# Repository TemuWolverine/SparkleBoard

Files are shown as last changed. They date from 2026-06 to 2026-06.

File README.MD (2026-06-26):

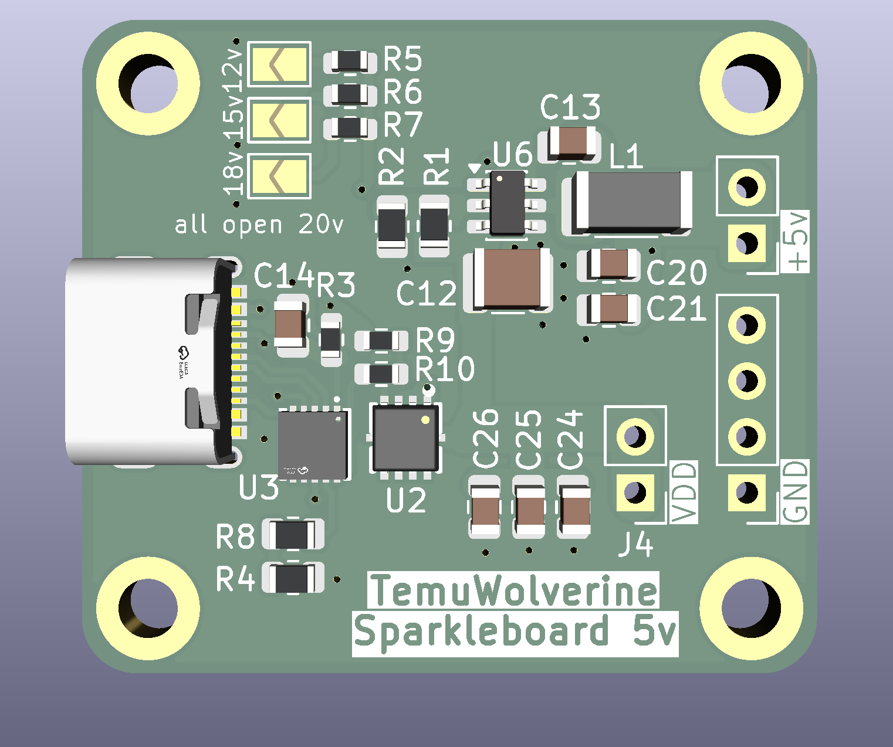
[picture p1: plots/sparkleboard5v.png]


# SparkleBoard 5v (WIP)
SparkleBoard is a USB-PD power board that provides two power rails - one is user selectable from 12v, 15v, 18v or 20v (if the USB-PD power brick supports it) by using jumpers. The other power rail is 5v for microcontrollers.

Amperage defaults to 2a, can be set to 3.25a by cutting JP1

## 5v  -> 3.3v
5v rail is provided via a buck converter - [AP63205](https://www.diodes.com/part/view/AP63205), an inexpensive fixed voltage buck converter from Diodes.

If you wanted 3.3v, this could be achieved by swapping out the chip for the AP63203, and changing the inductor to 3.9uH (from 4.7uH). The rest of the circuit design remains the same according to the manufacturer.

> Note: the AP63200/AP63201 are not fixed voltage output IC's and require additional circuitry with different values and are **NOT** drop in replacements.

## Datasheets
* [AP63205](https://www.diodes.com/datasheet/download/AP63200-AP63201-AP63203-AP63205.pdf)
* [HUSB238](https://www.hynetek.com/uploadfiles/site/219/news/aabbbbdb-48c9-4a44-a6dc-2c15f53282e6.pdf)

## References
* [Sparkfun Babybuck](https://github.com/sparkfun/Buck_Regulator_AP63203/tree/main) (AP6320***3***)
* [Adafruit HUSB238 breakout board](https://github.com/adafruit/Adafruit-USB-Type-C-Power-Delivery-Dummy-Breakout-PCB/tree/main)

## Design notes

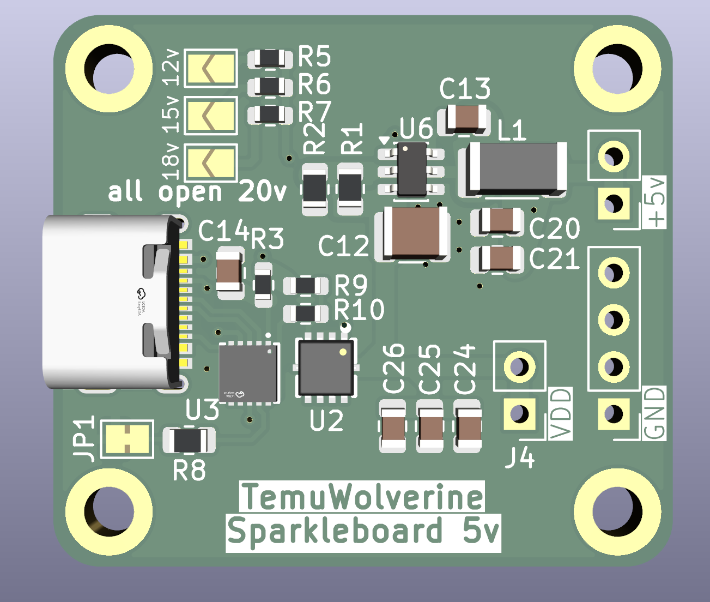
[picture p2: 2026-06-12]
image.png

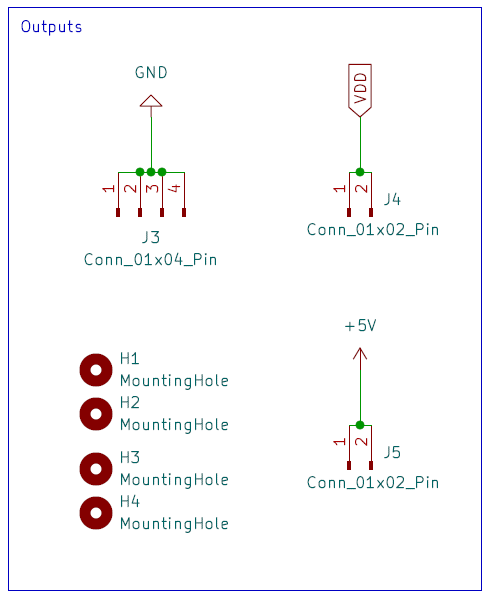
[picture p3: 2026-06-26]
plots/Pins.png

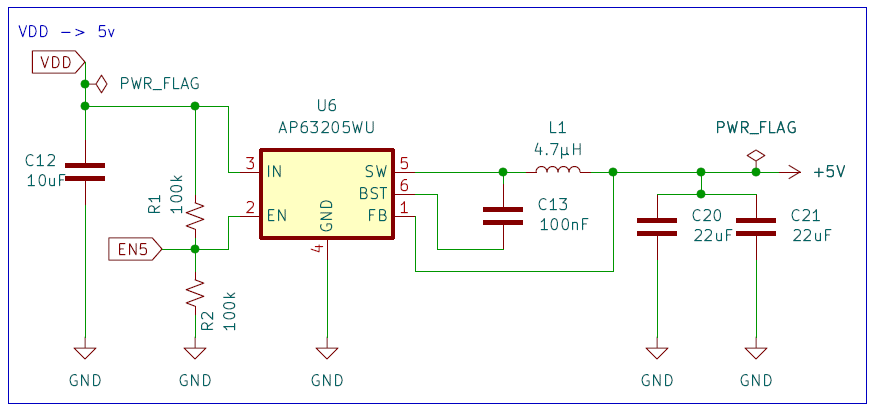
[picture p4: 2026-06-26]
plots/Buck.png

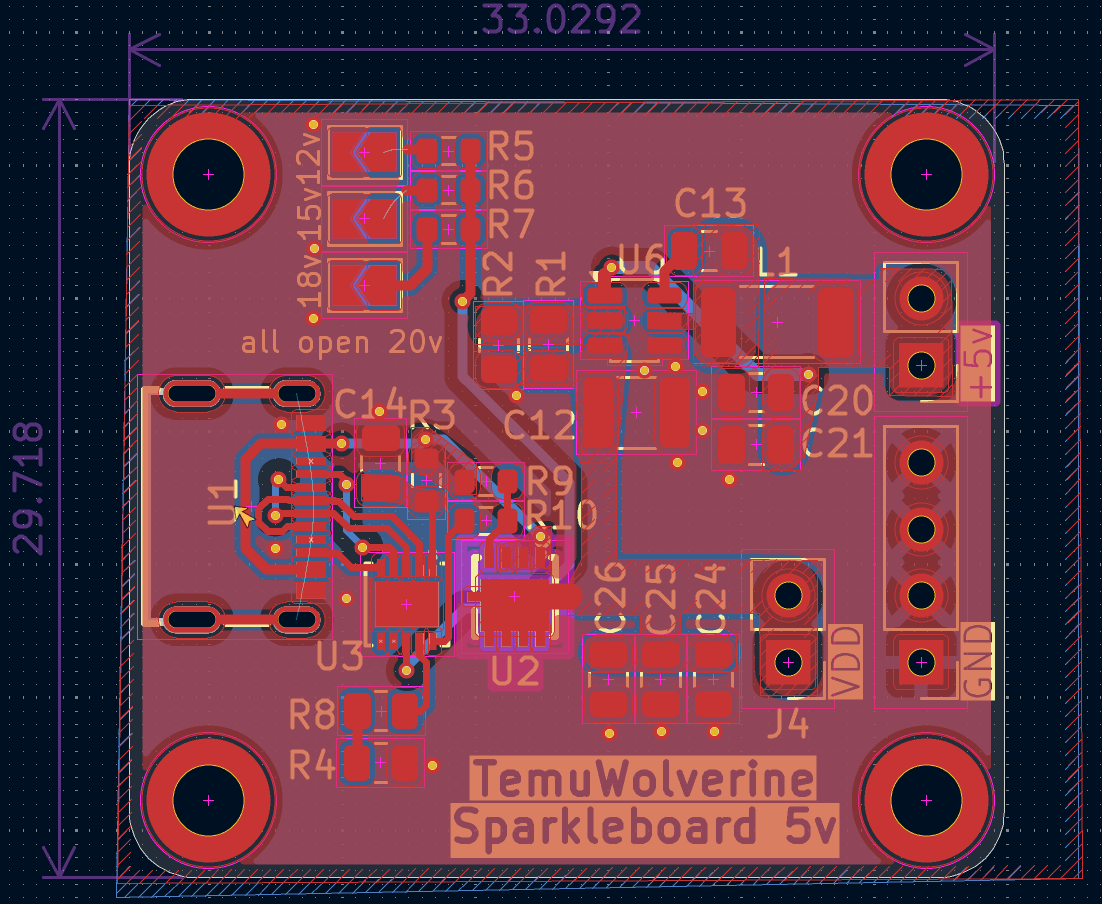
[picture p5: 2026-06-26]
plots/pcb_both.png

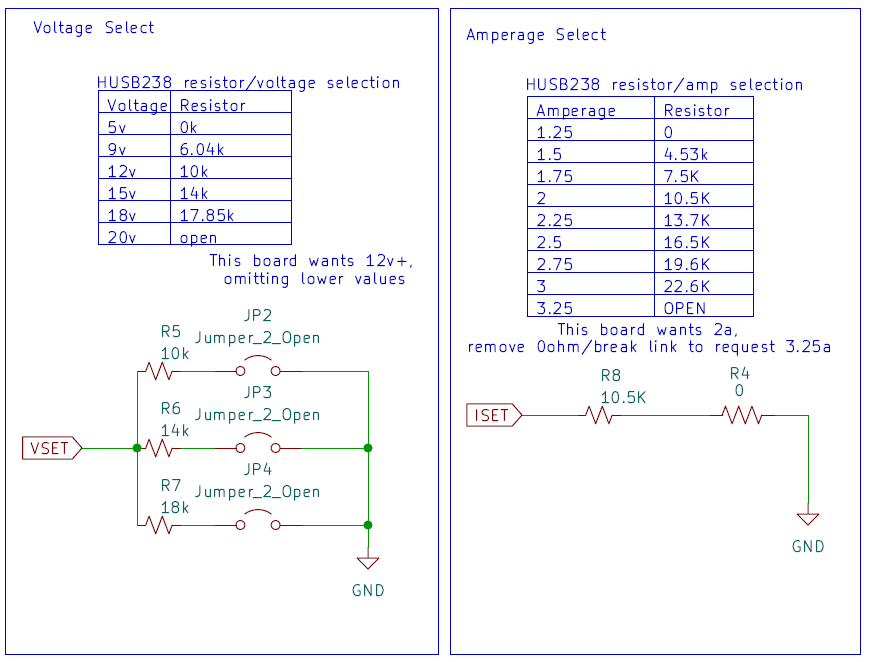
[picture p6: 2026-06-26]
plots/V_A_select.png

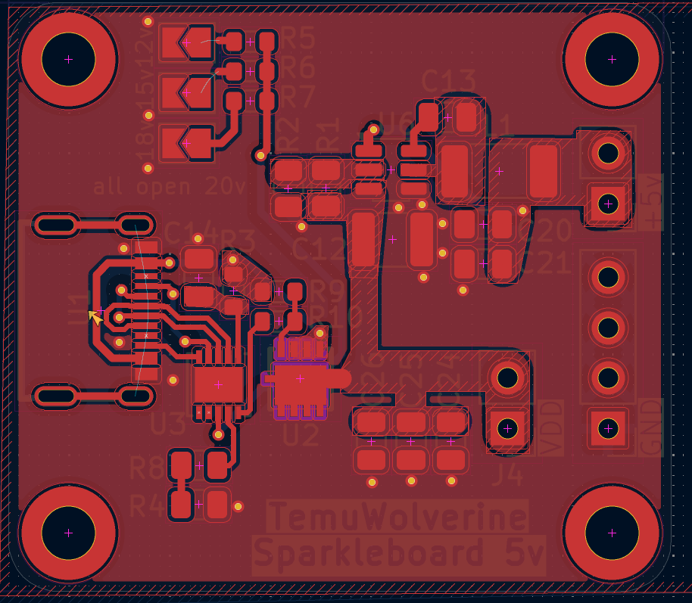
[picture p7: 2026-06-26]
plots/pcb_front.png

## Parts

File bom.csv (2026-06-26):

Designator | Footprint | Quantity | Value | LCSC Part #
C12 | 1210 | 1 | 10uF
C13 | 0805 | 1 | 100nF
C14 | 0805 | 1 | 1uF
C20, C21 | 0805 | 2 | 22uF
C24, C25, C26 | 0805 | 3 | 4.7uF
J3 | PinHeader_1x04_P2.54mm_Vertical | 1 | Conn_01x04_Pin
J4, J5 | PinHeader_1x02_P2.54mm_Vertical | 2 | Conn_01x02_Pin
JP2, JP3, JP4 | SolderJumper-2_P1.3mm_Open_TrianglePad1.0x1.5mm | 3 | Jumper_2_Open
L1 | 2010 | 1 | 4.7μH
R1, R2 | 0805 | 2 | 100k
R10 | 0603 | 1 | 5.1k
R3 | 0603 | 1 | 10
R4 | 0805 | 1 | 0
R5 | 0603 | 1 | 10k
R6 | 0603 | 1 | 14k
R7 | 0603 | 1 | 18k
R8 | 0805 | 1 | 10.5K
R9 | 0603 | 1 | 49.9k
U1 | TYPE-C-SMD_UC.01.51-11-0017 | 1 | C9900066641
U2 | PRPAK-8_L3.0-W3.0-P0.65-BL-EP | 1 | AONR21307
U3 | TDFN-10_L3.0-W3.0-P0.50-TL-EP | 1 | HUSB238
U6 | TSOT-23-6 | 1 | AP63205WU

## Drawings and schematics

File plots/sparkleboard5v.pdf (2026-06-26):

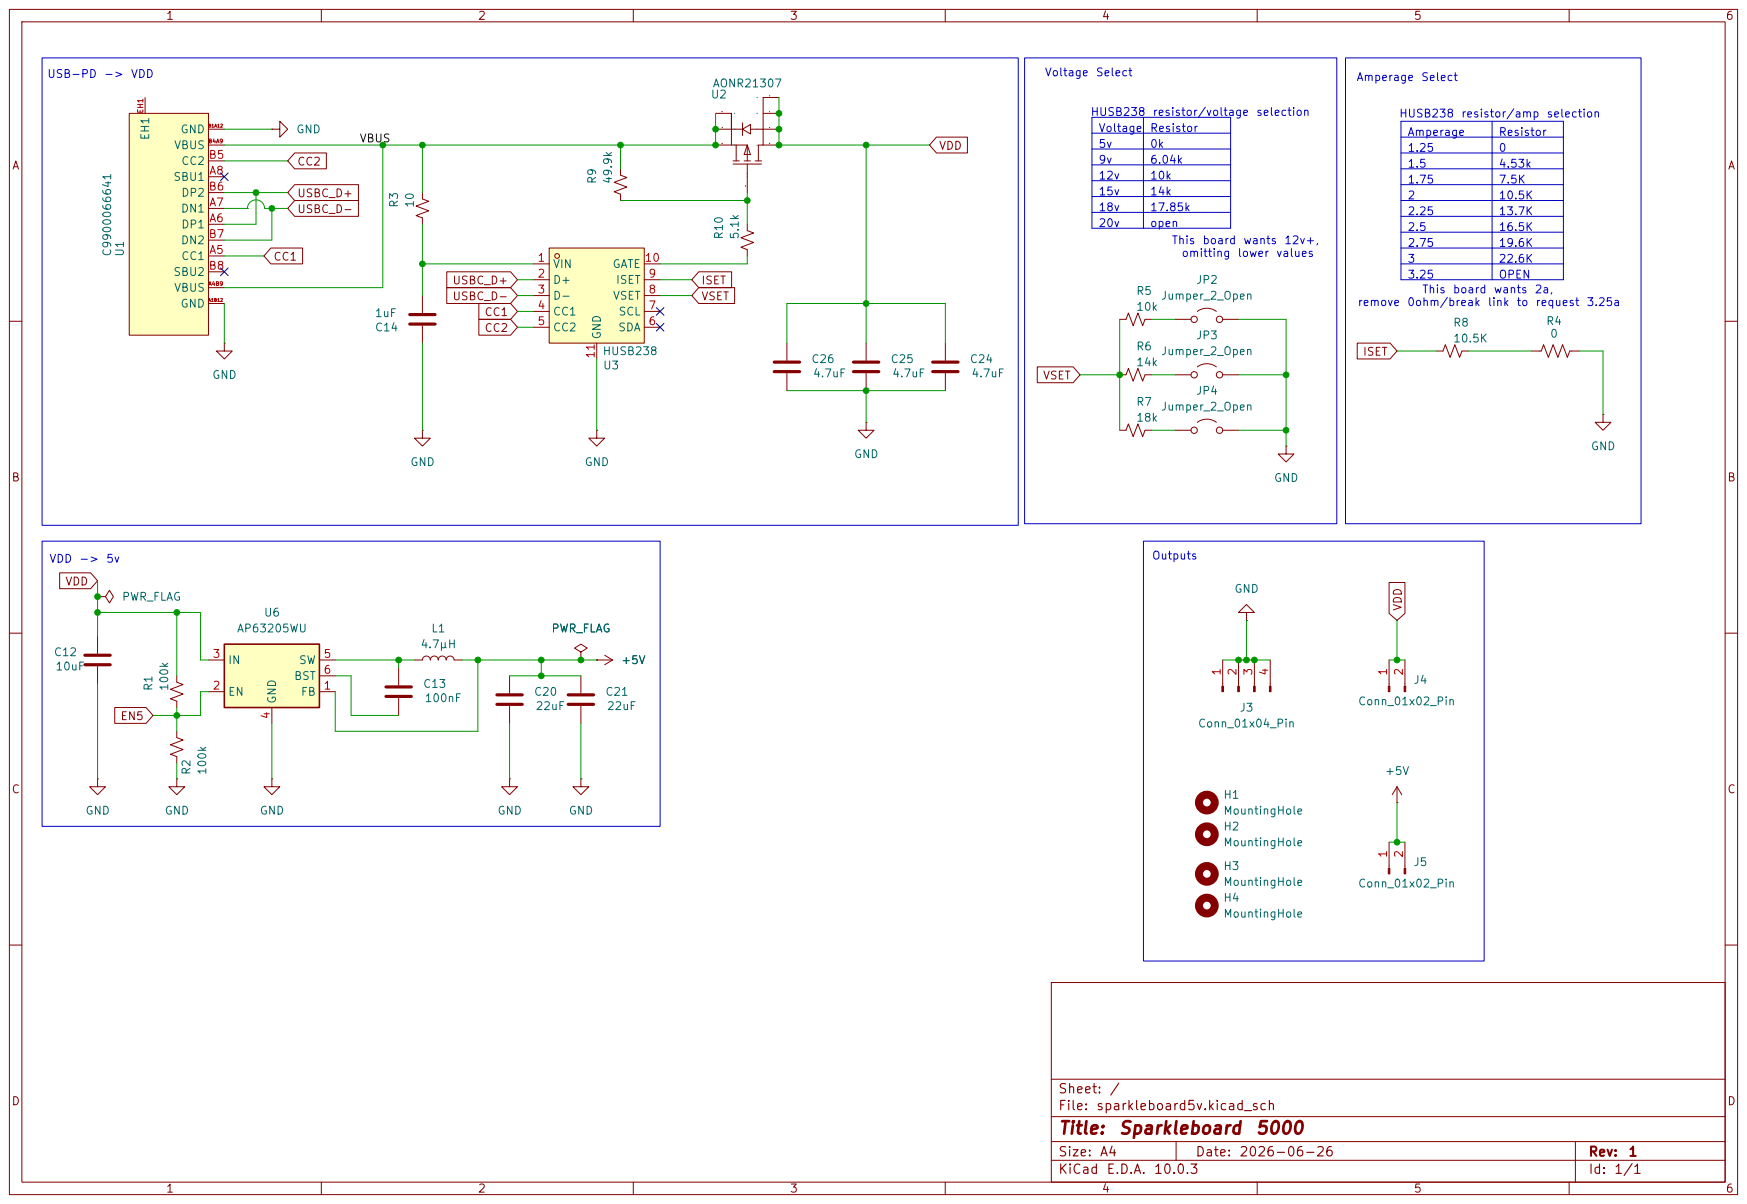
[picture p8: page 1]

Amperage Select This board wants 2a, remove 0ohm/break link to request 3.25a HUSB238 resistor/voltage selection Outputs +5V PWR_FLAG

Amperage | Resistor 1.25 0

2 | 10.5K
2.25 | 13.7K
2.5 | 16.5K

omitting lower values VDD -> 5v

Size: A4 | Rev: 1
KiCad E.D.A. 10.0.3 | Id: 1/1

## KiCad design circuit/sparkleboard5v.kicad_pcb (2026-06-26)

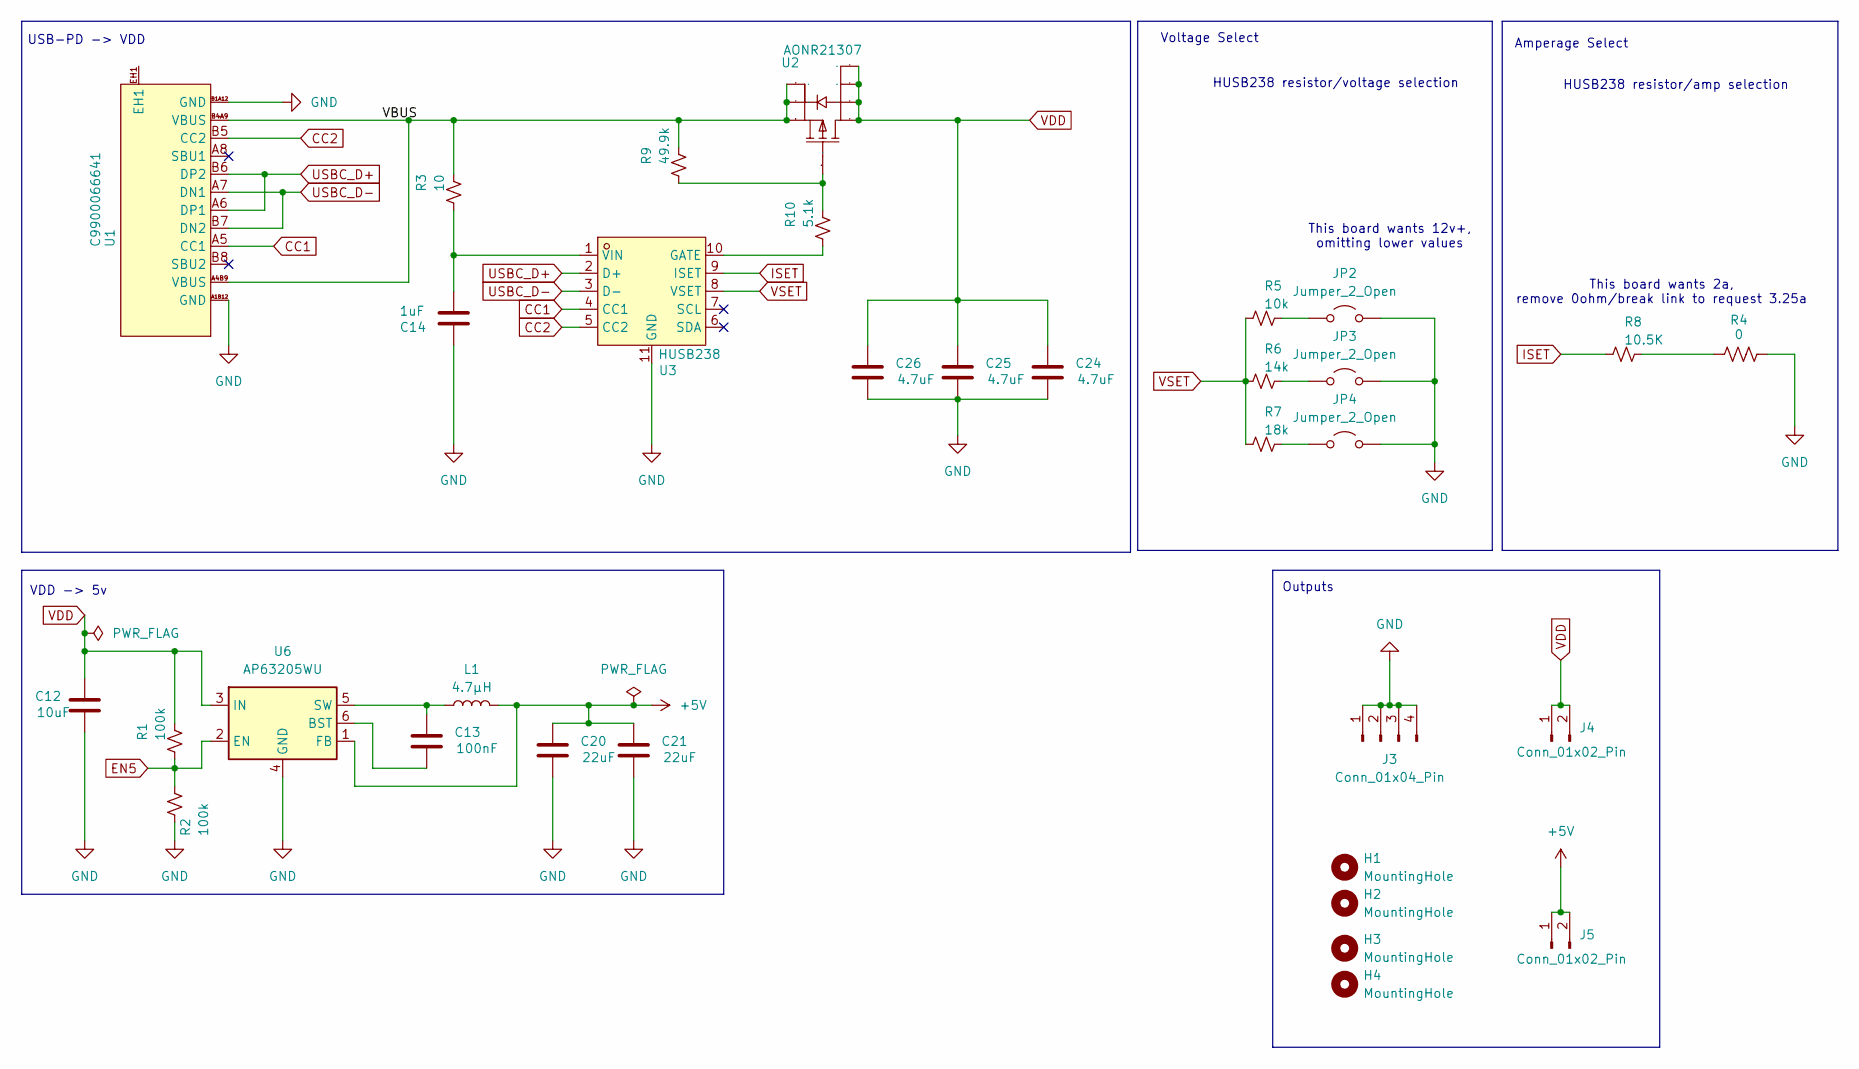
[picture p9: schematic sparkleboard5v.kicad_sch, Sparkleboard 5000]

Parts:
C12: 10uF; C_1210_3225Metric
C13: 100nF; C_0805_2012Metric
C14: 1uF; C_0805_2012Metric
C20, C21: 22uF; C_0805_2012Metric
C24, C25, C26: 4.7uF; C_0805_2012Metric
H1, H2, H3, H4: MountingHole; MountingHole_2.7mm_M2.5_DIN965_Pad
J3: Conn_01x04_Pin; PinHeader_1x04_P2.54mm_Vertical
J4, J5: Conn_01x02_Pin; PinHeader_1x02_P2.54mm_Vertical
JP2, JP3, JP4: Jumper_2_Open; SolderJumper-2_P1.3mm_Open_TrianglePad1.0x1.5mm
L1: 4.7μH; L_2010_5025Metric
R1, R2: 100k; R_0805_2012Metric
R3: 10; R_0603_1608Metric
R4: 0; R_0805_2012Metric
R5: 10k; R_0603_1608Metric
R6: 14k; R_0603_1608Metric
R7: 18k; R_0603_1608Metric
R8: 10.5K; R_0805_2012Metric
R9: 49.9k; R_0603_1608Metric
R10: 5.1k; R_0603_1608Metric
U1: C9900066641; TYPE-C-SMD_UC.01.51-11-0017; Manufacturer Part UC.01.51-11-0017,typec; LCSC Part Name UC.01.51-11-0017,typec
U2: AONR21307; PRPAK-8_L3.0-W3.0-P0.65-BL-EP; Manufacturer Part AONR21307; LCSC Part Name 1个P沟道 耐压:30V 电流:24A
U3: HUSB238; TDFN-10_L3.0-W3.0-P0.50-TL-EP; Manufacturer Part HUSB238; LCSC Part Name HUSB238
U6: AP63205WU; TSOT-23-6

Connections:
+5V: C20.1, C21.1, J5.1, J5.2, L1.2, U6.1 (FB)
/VBUS: R3.2, R9.2, U1.A4B9 (VBUS), U1.B4A9 (VBUS), U2.1 (S), U2.2 (S), U2.3 (S)
CC1: U1.A5 (CC1), U3.4 (CC1)
CC2: U1.B5 (CC2), U3.5 (CC2)
EN5: R1.1, R2.2, U6.2 (EN)
GND: C12.2, C14.1, C20.2, C21.2, C24.2, C25.2, C26.2, J3.1, J3.2, J3.3, J3.4, JP2.2 (B), JP3.2 (B), JP4.2 (B), R2.1, R4.1, U1.A1B12 (GND), U1.B1A12 (GND), U3.11 (GND), U6.4 (GND)
ISET: R8.1, U3.9 (ISET)
unnamed: JP2.1 (A), R5.2
unnamed: JP3.1 (A), R6.2
unnamed: JP4.1 (A), R7.2
unnamed: R4.2, R8.2
unnamed: R9.1, R10.2, U2.4 (G)
unnamed: R10.1, U3.10 (GATE)
unnamed: C14.2, R3.1, U3.1 (VIN)
unnamed: C13.2, U6.6 (BST)
unnamed: C13.1, L1.1, U6.5 (SW)
USBC_D+: U1.A6 (DP1), U1.B6 (DP2), U3.2 (D+)
USBC_D-: U1.A7 (DN1), U1.B7 (DN2), U3.3 (D-)
VDD: C12.1, C24.1, C25.1, C26.1, J4.1, J4.2, R1.2, U2.5 (D), U2.6 (D), U2.7 (D), U2.8 (D), U6.3 (IN)
VSET: R5.1, R6.1, R7.1, U3.8 (VSET)

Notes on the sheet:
This board wants 12v+, omitting lower values
Outputs
USB-PD -> VDD
HUSB238 resistor/voltage selection
This board wants 2a, remove 0ohm/break link to request 3.25a
VDD -> 5v
Amperage Select
HUSB238 resistor/amp selection
Voltage Select

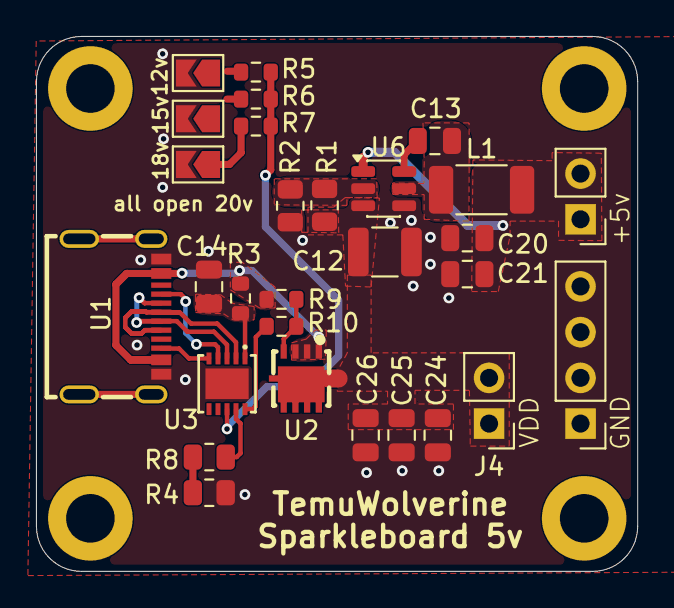
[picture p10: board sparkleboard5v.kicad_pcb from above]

Board: 2 copper layers, 33.4 x 29.7 mm, 33 parts (0 on the bottom side), 20 nets.

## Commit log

2026-06-10 happy with "v1"
    [sparkleboard5v.kicad_pcb, sparkleboard5v.kicad_sch]
2026-06-12 tweaked spacing, updated readme
    [sparkleboard5v.kicad_pcb, sparkleboard5v.kicad_sch]
2026-06-26 Updated board, added more plots for reddit review
    [sparkleboard5v.kicad_pcb, sparkleboard5v.kicad_sch]
2026-06-26 updated gitignore to add bom
    [bom.csv]
